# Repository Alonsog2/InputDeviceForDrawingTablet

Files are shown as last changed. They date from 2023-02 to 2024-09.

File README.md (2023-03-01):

# Input device for drawing tablet (and now, MIDI device too)

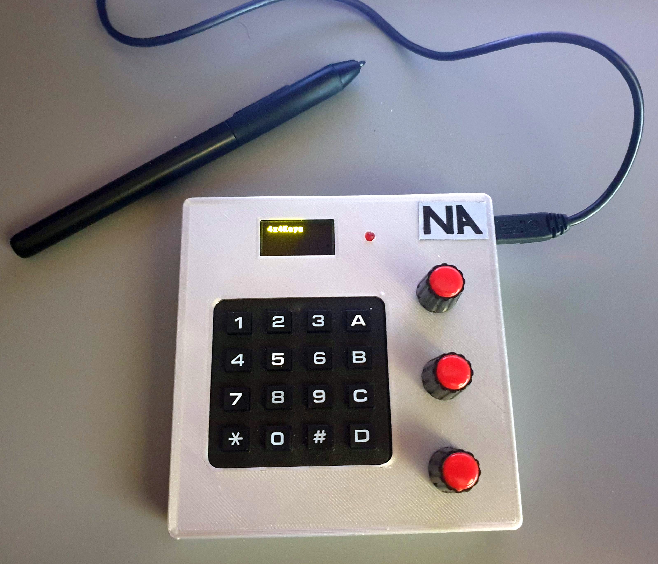
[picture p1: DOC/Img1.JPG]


This DIY device is recognized by any computer as a USB keyboard. Nor specific driver, neither other software is needed.
Inside, there is only an Arduino Pro Micro, a 4x4 keyboard matrix and 3 rotary encoders.

I use it with Krita but can be programmed with any key code combination, so it can work with any other drawing software.
The 16 keys and the 3 knobs/push buttons can send any combination of key codes.
The preprogrammed key codes can be modified easily, depending on your preferences, changing the corresponding program lines.

I have programmed the first knob for "rotate canvas" function (and reset the rotation if you press the knob)

The second knob is assigned for zooming (and reset the zoom to "fit page" pressing the knob)

The third knob is for resizing the brush. In this case, pushing the knob toggle the 'erase mode' of the brush.

Bear in mind that, in some cases, the shortcuts in my Krita setup are not the standard ones, so pay attention to this.

In this new version, a display shows the info about what key or action is performed. 

LocalShift function:
Now, the system can have to different sets of keys. Let's call them 'primary set' and 'secondary set'.
A key must be defined as 'LocalShift' (by default the key A) and it opperates as follow, allowing access to a different set of configurations for the rest of 15 keys.

Pressing once 'local shift' the system enters in temporary 'local shift' mode (the LED blinks), and after the next stroke in any key, the system will return to normal mode (and the LED turns off).

Pressing twice 'local shift' the system enters in 'local shift' mode (the LED turns on) , and remains in this mode until deactivated by a new press on 'local shift' and the system will return to normal mode (and the LED turns off).

A long press on 'local shift' will switch between 'normal mode' and 'Test mode' (the LED blinks less frequently). While in 'test mode' no keystrokes are sent to the computer but displayed on the screen. Handy for checking how all the keys are configured. To exit 'test mode', long-press 'local shift' again.

MIDI device:
Now, the system can act as a MIDI controller too. 
A long press (more than 2 seconds) on 'Knob #1' will switch between 'Keyboard mode' and 'MIDI mode'. In this case, the device will be recognized as a MIDI controller by the computer. All the parameters related to MIDI mode are defined in the setup file and are independent of the keyboard mode.

All the config parameters are located in the file 'Setup1.h'. It is possible to use different config files, such as 'Setup2.h'... etc., changing the corresponding line in the main program (just in case you have several devices with different configurations).

For more information, schematic, 3D printer file, etc. see the files in the DOC folder.

You can see a video with an example of use: [Example in youtube](https://youtu.be/WGJYHXOumJs)

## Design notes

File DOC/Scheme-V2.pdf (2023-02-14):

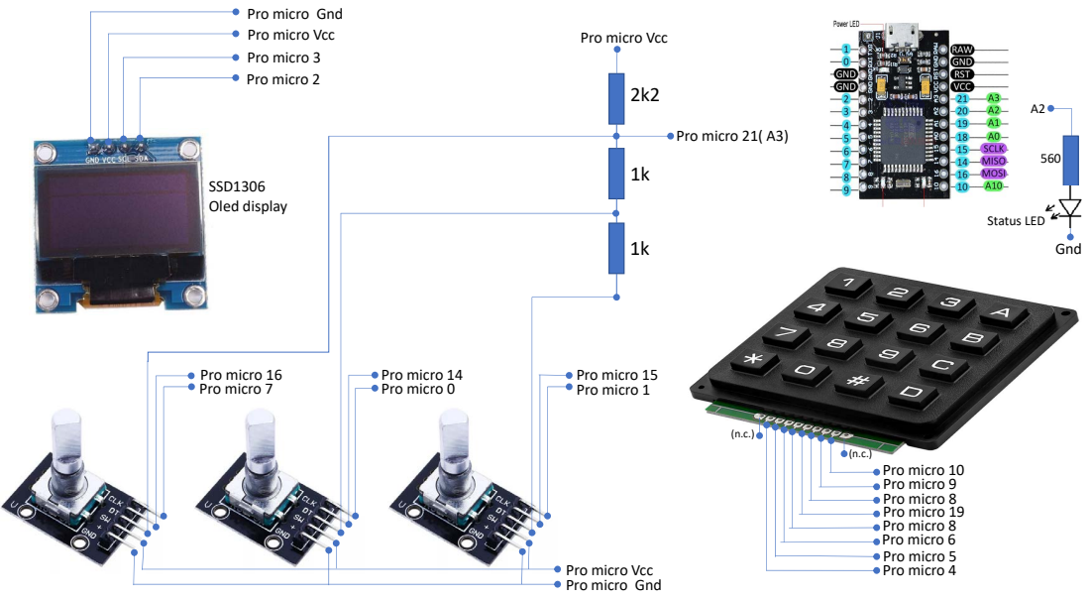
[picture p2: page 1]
Pro micro 21( A3); Pro micro 16 Pro micro 7; Pro micro 14 Pro micro 0; Pro micro 15 Pro micro 1; Pro micro 9 Pro micro 8 Pro micro 19 Pro micro 8 Pro micro 6 Pro micro 5 Pro micro 4; Pro micro 10; Gnd; Status LED; SSD1306 Oled display

Pro micro Gnd
Pro micro Vcc
Pro micro 3
Pro micro 2

# Key settings

Q (Freehand select. temp.) | T (Move tool temp.) | Ctrl‐D (Deselect) | Local Shift
Tab (Only canvas) | S (Isolate layer) | R (Select layer) | BackSpace (Fill with backColor)
Shift | Ctrl < (Shade color selector) | Z (Pie menu) | Ctrl SPC (Zoom)
Ctrl (Color picker) | Ctrl Z (Undo) | M (Mirror) | SPC (Pan canvas)

4 6

Rotate
canvas

7 9

Brush
size

‐ +

Zoom
canvas

5 (Reset rotation)

2 (Fit page)

E (Toggle eraser)

First press ‐> Temporary Shift mode Second press‐> Permanent Shift mode Third press ‐> Return to normal mode (main settings configuration , see previous page)

Long press ‐> Enter in Test mode (no keys are sent to the computer) Long press again ‐> Exit test mode

While in test mode ‐> Long press (2 seconds) “Reset rotation” button, change to MIDI mode

LocalShift:

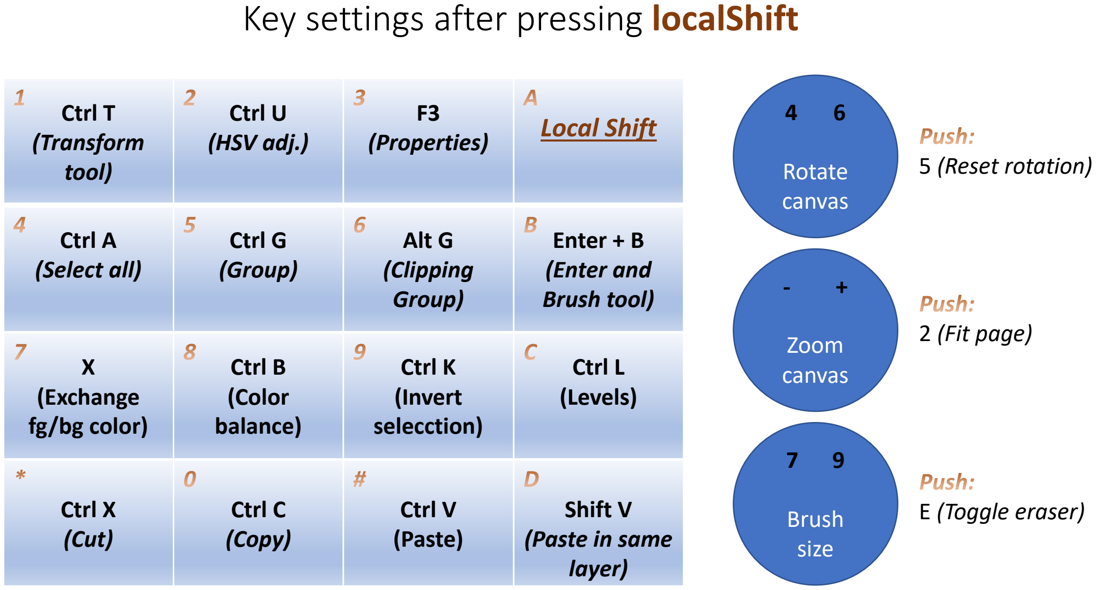
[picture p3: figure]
Key settings after pressing localShift; Ctrl T (Transform tool); Ctrl U (HSV adj.); F3 (Properties); Local Shift; X (Exchange fg/bg color); Ctrl B (Color balance); Ctrl K (Invert selecction); Ctrl L (Levels); Rotate canvas; Brush size; Zoom canvas; 5 (Reset rotation); 2 (Fit page); E (Toggle eraser)

Ctrl A (Select all) | Ctrl G (Group) | Alt G (Clipping Group) | Enter + B (Enter and Brush tool)
Ctrl X (Cut) | Ctrl C (Copy) | Ctrl V (Paste) | Shift V (Paste in same layer)

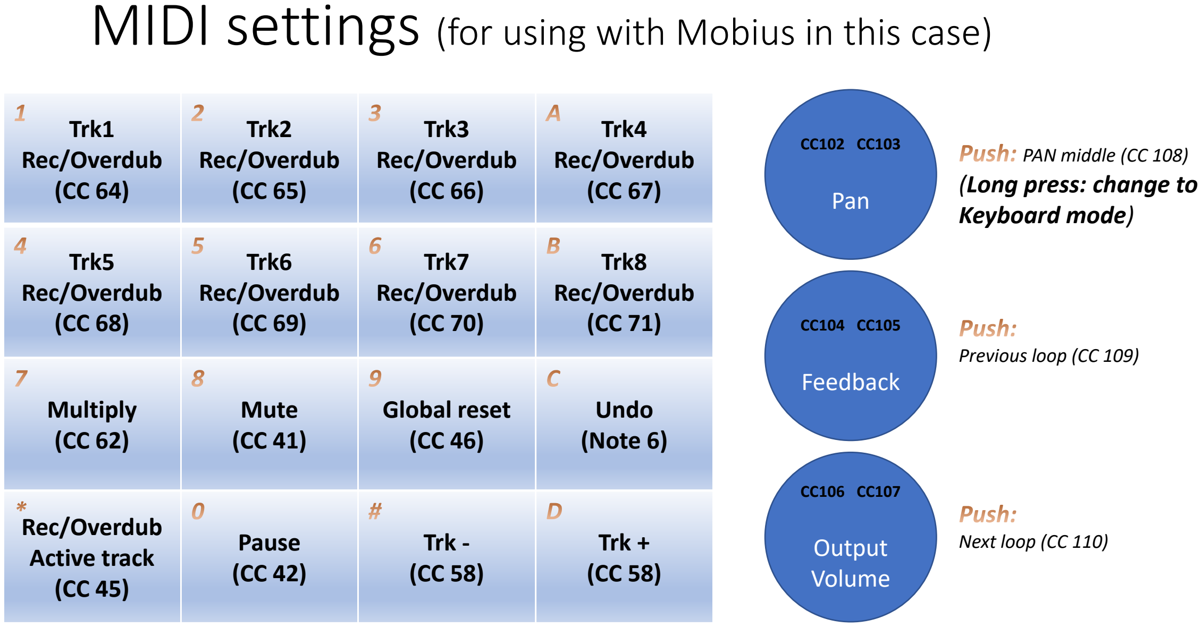
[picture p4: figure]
Trk1 Rec/Overdub (CC 64); Trk2 Rec/Overdub (CC 65); Trk3 Rec/Overdub (CC 66); Trk4 Rec/Overdub (CC 67); Trk5 Rec/Overdub (CC 68); Trk6 Rec/Overdub (CC 69); Trk7 Rec/Overdub (CC 70); Trk8 Rec/Overdub (CC 71); Multiply (CC 62); Mute (CC 41); Global reset (CC 46); Undo (Note 6); Rec/Overdub Active track (CC 45); Pause (CC 42); Trk ‐ (CC 58); Trk + (CC 58); Pan; Output Volume; Feedback; PAN middle (CC 108) (Long press: change to Keyboard mode); Previous loop (CC 109); Next loop (CC 110)

## MIDI settings (for using with Mobius in this case)

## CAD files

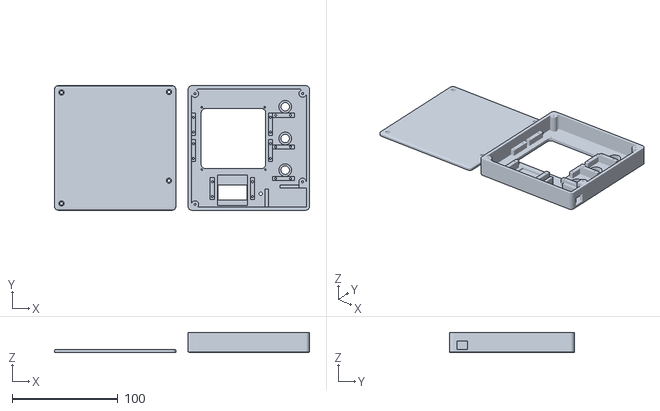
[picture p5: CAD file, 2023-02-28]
DOC/InputDeviceForDrawingTablet-3D-box.stl
241.5 x 118.1 x 19.0

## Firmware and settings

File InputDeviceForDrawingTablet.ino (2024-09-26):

/* This project as been made by Jose Ignacio Alonso
   For more information, visit https://github.com/Alonsog2/InputDeviceForDrawingTablet
*/


#define SETUP_TO_USE "Setup1.h"

//#define INIT_IN_ TEST_MODE           // uncomment this line while testing the sketch, to prevent sending keystrokes to the computer


#define CF(s) ((const __FlashStringHelper *)s)

///////////////////////////////////////////////////////////////////////////////   4X4 keyboard   ///////////////////////////////////////////////////////

#include <Keyboard.h>               // library for USB communication

#include <Keypad.h>                 // library for controlling 4x4 keys
const byte ROWS = 4; // rows
const byte COLS = 4; // columns
char keys[ROWS][COLS] = {           // characters behind number 9 are the next in the ASCII secuence, just to make easier the indexation (from 0 to 15)
  {'0', '1', '2', '3'},
  {'4', '5', '6', '7'},
  {'8', '9', ':', ';'},
  {'<', '=', '>', '?'}
};

enum LOCAL_SHIFT_MODES {
  NO_LOCAL_SHIFT = 0,
  LOCAL_SHIFT_TEMP,                         // Pressing once localShift key. Then, after pressing any other key, the system automaticaly return to NO_LOCAL_SHIFT mode
  LOCAL_SHIFT_LOCKED,                       // Pressing twice localShift key. Then the system remains in localShift mode until localShift key is pressed again.
};

LOCAL_SHIFT_MODES localShiftMode = NO_LOCAL_SHIFT;

#define millis_LED_LocalShift 150
#define millis_LED_TestMode_High 50
#define millis_LED_TestMode_Low 900
#define millis_LED_MidiMode 1000
#define millis_LONG_PRESS_SwitchMIDImode 2000

long lastMillis_LED_Status = 0;

char key;

//////////////////////////////////////////////////////////////////////  ROTARY ENCODERS  ///////////////////////////////////////////////////////////////

#include <Encoder.h>

#define N_ENCODERS 3

#define INX_ENCODER_UP 1
#define INX_ENCODER_DOWN 0

#define MILLIS_DISPLAYING_ENCODER_INFO 600
boolean bEncodersMoved = false;
unsigned long lastTimeEncoderMoved = 0;


//////////////////////////////////////////////////////////////////////   Analog buttons (3 keys readed in only one analogic input)  ////////////////////////

#include <AnalogMultiButton.h>

// set how many buttons you have connected
#define ENCODER_BUTTONS_TOTAL N_ENCODERS

// find out what the value of analogRead is when you press each of your buttons and put them in this array
// you can find this out by putting Serial.println(analogRead(ENCODER_BUTTONS_ANALOG_PIN)); in your loop() and opening the serial monitor to see the values
// make sure they are in order of smallest to largest
const int ENCODER_BUTTONS_VALUES[ENCODER_BUTTONS_TOTAL] = {0, 315, 482};

// you can also define constants for each of your buttons, which makes your code easier to read
// define these in the same order as the numbers in your BUTTONS_VALUES array, so whichever button has the smallest analogRead() number should come first
enum ENCODER_BUTTONS {
  ENCODER2_BUTTON = 0,
  ENCODER1_BUTTON,
  ENCODER0_BUTTON
};


#include SETUP_TO_USE

#include "MIDI.h"


Keypad keypad = Keypad( makeKeymap(keys), rowPins, colPins, ROWS, COLS );

// make an AnalogMultiButton object, pass in the pin, total and values array
AnalogMultiButton encoder_buttons(ENCODER_BUTTONS_ANALOG_PIN, ENCODER_BUTTONS_TOTAL, ENCODER_BUTTONS_VALUES);

#ifdef INIT_IN_ TEST_MODE
  boolean testMode = true;
#else
  boolean testMode = false;
#endif


#define SECONDS_UNTIL_SCREENSAVER_IF_SYSTEMUNLOCKED 300   // (300/60) = 5 minutes
#define SECONDS_UNTIL_SCREENSAVER_IF_SYSTEMLOCKED 5     

unsigned long lastTimeActionByUser = 0;
unsigned long millisIntervalUntilScreenSaverIfSystemUnlocked = (unsigned long)(SECONDS_UNTIL_SCREENSAVER_IF_SYSTEMUNLOCKED) * 1000;
unsigned long millisIntervalUntilScreenSaverIfSystemLocked = (unsigned long)(SECONDS_UNTIL_SCREENSAVER_IF_SYSTEMLOCKED) * 1000;
unsigned long millisIntervalScreenSaver = millisIntervalUntilScreenSaverIfSystemUnlocked;
boolean bScreenSaverON = false;
boolean bSystemLocked = false;



/////////////////////////////////////////////////////// setup //////////////////////////////////////////////////////////////

void setup() {
  Serial.begin(115200);
  delay(3000);
  Serial.println(F("Init"));

  if (DeviceModel != KEYBOARD_ONLY) {
    initMIDI();
  }

  if (bUseDisplay) {
    initDisplay();
  }

  //Switch off the serial port leds
  pinMode(LED_BUILTIN_TX, INPUT);
  pinMode(LED_BUILTIN_RX, INPUT);

  pinMode(pin_LED_Status, OUTPUT);                       // LED for localShift indication

  refreshLED_Status();

  keypad.setDebounceTime(50);

  Keyboard.begin();

  encoder_buttons.update();                              // just for clearing status

  Serial.println(F("EndSetup"));
}




/////////////////////////////////////////////////////// loop //////////////////////////////////////////////////////////////

void loop() {
  byte keyIndex;

  encoder_buttons.update();                                                                  // check encoder_buttons only once for the whole loop
  
  if (bCheckMIDIpedalIn4x4keysMode){                                                         // Checking MIDIpedal while in 4x4keys mode 
    if (encoder_buttons.onPressAndAfter(ENCODER2_BUTTON, 0)) {                               // 0= Detect only the first pressing
       pressedMIDIKey(actionsMIDIEncodersButtons, 2);                                        // MIDIpedal is button #2       
    }

    if (encoder_buttons.onRelease(ENCODER2_BUTTON)) {
      releasedMIDIKey(actionsMIDIEncodersButtons, 2);
      clearAreaBottomDisplay();
    }
  }

  unsigned long millisNow = millis();
  if ( abs(millisNow - lastTimeActionByUser) > millisIntervalScreenSaver ) {
    if (! bScreenSaverON) {
      clearAllDisplay(); 
      bScreenSaverON = true;
    }
    bSystemLocked = true;
  }

  if (bSystemLocked) {
    if (keypad.getKeys()) {
      for (int i = 0; i < LIST_MAX; i++) {                       // Scan the whole key list.
        if ( keypad.key[i].stateChanged ) {                      // Only find keys that have changed state.
          keyIndex = keypad.key[i].kchar - char('0');            // get the index from 0 to 15
          if (keyIndex == index_LocalShiftKey) {
            if (keypad.key[i].kstate == HOLD) {
              bSystemLocked = false;
            }
          }
        }
      }
      displayStatus();
      resetTimeScreenSaver();      
    }
    if (bSystemLocked) {
      millisIntervalScreenSaver = millisIntervalUntilScreenSaverIfSystemLocked;
      return;
    } else {
      millisIntervalScreenSaver = millisIntervalUntilScreenSaverIfSystemUnlocked;
    }
  }

  // Fills kpd.key[ ] array with up-to 10 active keys. Returns true if there are ANY active keys.
  if (keypad.getKeys()) {
    for (int i = 0; i < LIST_MAX; i++) {                       // Scan the whole key list.
      if ( keypad.key[i].stateChanged ) {                      // Only find keys that have changed state.
        resetTimeScreenSaver();
        bEncodersMoved = false;
        keyIndex = keypad.key[i].kchar - char('0');            // get the index from 0 to 15
        switch (keypad.key[i].kstate) {                        // Report active key state : IDLE, PRESSED, HOLD, or RELEASED
          case PRESSED:
            if (MIDImode) {
              pressedMIDIKey(actionsMIDI, keyIndex);
              break;
            }

            if (keyIndex == index_LocalShiftKey) {
              switch (localShiftMode) {
                case NO_LOCAL_SHIFT:
                  localShiftMode = (testMode) ? LOCAL_SHIFT_LOCKED : LOCAL_SHIFT_TEMP;  // In testMode, always go to LOCAL_SHIFT_LOCKED (skiping LOCAL_SHIFT_TEMP)
                  break;
                case LOCAL_SHIFT_TEMP:
                  localShiftMode = LOCAL_SHIFT_LOCKED;
                  lastMillis_LED_Status = 0;
                  break;
                case LOCAL_SHIFT_LOCKED:
                  localShiftMode = NO_LOCAL_SHIFT;
                  break;
              }
              Keyboard.releaseAll();                         // just in case some other previous key still pressed...
              clearAllDisplay();
              displayStatus();
              break;
            }

            if (! testMode) {
              sendKeyPressed( ( (localShiftMode == NO_LOCAL_SHIFT) ? actions : actions_LocalShift), keyIndex);
            }

            if (localShiftMode == NO_LOCAL_SHIFT) {
              displayKeyLabel( CF( actions_labels[keyIndex]));
            } else {
              displayKeyLabel( CF( actions_LocalShift_labels[keyIndex]));
            }
            break;

          case HOLD:
            if (testModeEnabled && (keyIndex == index_LocalShiftKey)) {  // Switch test mode
              Keyboard.releaseAll();                                     // just in case some other previous key still pressed...
              localShiftMode = NO_LOCAL_SHIFT;                           // After enter or exit testMode, always return to NO_LOCAL_SHIFT modee2
              testMode = !testMode;
              displayStatus();
            }
            break;

          case RELEASED:
            if (MIDImode) {
              releasedMIDIKey(actionsMIDI, keyIndex);
              clearAreaBottomDisplay();
              break;
            }

            if (keyIndex == index_LocalShiftKey) {
              Keyboard.releaseAll();                        // just in case some other previous key still pressed...
              break;
            }
            if (localShiftMode == LOCAL_SHIFT_TEMP) {
              localShiftMode = NO_LOCAL_SHIFT;
              Keyboard.releaseAll();
              displayStatus();
              refreshLED_Status();
            }

            sendKeyDepressed( ( (localShiftMode) ? actions_LocalShift : actions), keyIndex);
            clearAreaBottomDisplay();
            break;

            //case IDLE:
            //  msg = " IDLE.";
            //  break;
        }

        //Serial.print(F("Key "));
        //Serial.print(keypad.key[i].kchar);
      }
    }
  }
  refreshLED_Status();

  // check the ENCODERS
  if (bUseRotaryEncoders) {
    long newPositionEncoder;

    for (int nEncoder = 0; nEncoder < N_ENCODERS ; nEncoder++) {
      int indexUpDown = -1;

      newPositionEncoder = chekEncoderN(nEncoder);
      if (newPositionEncoder > 1) indexUpDown = INX_ENCODER_DOWN;
      if (newPositionEncoder < -1) indexUpDown = INX_ENCODER_UP;
      if (indexUpDown != -1) {
        if (MIDImode) { /////////////////////////////////////////////////////////////////// MIDI mode /////////////////////////////////////////
          if (MIDIencodersEqualUpDownCC[nEncoder]) { // MIDI encoder EqualUpDownCC
            byte channel = (actionsMIDIEncoders[nEncoder][MIDI_CHANNEL] == 0) ? GLOBAL_MIDI_CHANNEL : actionsMIDIEncoders[nEncoder][MIDI_CHANNEL];
            int value = MIDIvalRotaryEncoders[nEncoder];
            if (indexUpDown == INX_ENCODER_UP) {
              value += actionsMIDIEncoders[nEncoder][MIDI_IncrDecrStep];
              if (value > actionsMIDIEncoders[nEncoder][MIDI_ValMax]) {
                value = actionsMIDIEncoders[nEncoder][MIDI_ValMax];
              }
            }
            if (indexUpDown == INX_ENCODER_DOWN) {
              value -= actionsMIDIEncoders[nEncoder][MIDI_IncrDecrStep];
              if (value < actionsMIDIEncoders[nEncoder][MIDI_ValMin]) {
                value = actionsMIDIEncoders[nEncoder][MIDI_ValMin];
              }
            }

            MIDIvalRotaryEncoders[nEncoder] = value;
            sendCtrlChange_USB(actionsMIDIEncoders[nEncoder][MIDI_nCC], value, channel);
          } else {  // Dual UP/DOWN
            pressedMIDIKey( ((indexUpDown == INX_ENCODER_DOWN) ? actionsMIDIEncodersDOWN : actionsMIDIEncodersUP ),  nEncoder);
          }
          // End MIDI

        } else { ///////////////////////////////////////////////////////////////////// KEYBOARD mode /////////////////////////////////////////
          if (! testMode) {
            Keyboard.press(actions1Encoders[nEncoder][indexUpDown]);
            if (actions2Encoders[nEncoder][indexUpDown] != 0) {                    // if the value is other than 0, send it
              Keyboard.press(actions2Encoders[nEncoder][indexUpDown] );
            }
          }

          displayKeyLabel( (indexUpDown == INX_ENCODER_UP) ? CF(actionsEncoderIncr_labels[nEncoder]) : CF(actionsEncoderDecr_labels[nEncoder]));

          Keyboard.releaseAll();
          // End Keyboard
        }

        resetEncoderN(nEncoder);
        resetTimeScreenSaver();
        lastTimeEncoderMoved = millis();
        bEncodersMoved = true;
      }
    }
  }
  //


  // check ENCODER_BUTTONS  ////////////////////////////////////////////////////////////////////////////////////////
  if (bUseEncoderButtons) {
    int keyIndex = -1;
    //encoder_buttons has been updated at the begining of the loop

    // Check possible switch Keyboard/MIDI mode //////////////////////////////////
    if (DeviceModel == KEYBOARD_AND_MIDI || DeviceModel == MIDI_AND_KEYBOARD) {              // Device can switch between Keyboard and MIDI ?
      if (encoder_buttons.onPressAfter(ENCODER0_BUTTON, millis_LONG_PRESS_SwitchMIDImode)) { // The defined enconder for switching is pressed more than xxxx millis ?
        Keyboard.releaseAll();
        resetTimeScreenSaver();
        bEncodersMoved = false;
        switchMIDIAndKeyboardMode();
      }
    } ////////////////////////////////////////////////////////////////////////////

    if (encoder_buttons.onPressAndAfter(ENCODER0_BUTTON, 0)) {   // 0= Detect only the first pressing
      keyIndex = 0;
    } else if (encoder_buttons.onPressAndAfter(ENCODER1_BUTTON, 0)) {
      keyIndex = 1;
    } else if (encoder_buttons.onPressAndAfter(ENCODER2_BUTTON, 0) && (!bCheckMIDIpedalIn4x4keysMode)) {
      keyIndex = 2;
    }

    if (keyIndex != -1) {
      resetTimeScreenSaver();
      bEncodersMoved = false;
      if (MIDImode) {
        pressedMIDIKey(actionsMIDIEncodersButtons, keyIndex);
      } else {
        if (! testMode) {
          sendKeyPressed(actionsEncoder_Buttons, keyIndex);
        }
        displayKeyLabel( CF( actionsEncoder_labels[keyIndex]));
      }
    }

    // check if some encoder_button has been DEPRESSED
    keyIndex = -1;
    if (encoder_buttons.onRelease(ENCODER0_BUTTON)) {
      keyIndex = 0;
    } else if (encoder_buttons.onRelease(ENCODER1_BUTTON)) {
      keyIndex = 1;
    } else if (encoder_buttons.onRelease(ENCODER2_BUTTON) && (!bCheckMIDIpedalIn4x4keysMode)) {
      keyIndex = 2;
    }

    if (keyIndex != -1) {
      resetTimeScreenSaver();
      bEncodersMoved = false;
      if (MIDImode) {                                            // MIDI mode
        releasedMIDIKey(actionsMIDIEncodersButtons, keyIndex);
      } else {                                                   // Keyboard
        if (! testMode) {
          sendKeyDepressed(actionsEncoder_Buttons, keyIndex);
        }
      }
      clearAreaBottomDisplay();
    }

  } // End ENCODER_BUTTONS

  checklastTimeEncoderMoved();

} // loop




///////////////////////////////////////////////////////// other functions //////////////////////////////////////////////////////////////

void sendKeyPressed(char acts[ROWS * COLS][2], int keyIndex) {
  Keyboard.press(acts[keyIndex][0]);           // send the first action for the corresponding key
  if (acts[keyIndex][1] != 0) {                 // send the second value if not 0
    Keyboard.press(acts[keyIndex][1]);
  }
}



void sendKeyDepressed(char acts[ROWS * COLS][2], int keyIndex) {
  if (acts[keyIndex][1] != 0) {                  // invert the order when releasing the keys, send actions2 first (if needed)
    Keyboard.release(acts[keyIndex][1]);
  }
  Keyboard.release(acts[keyIndex][0]);           // and then actions1
}



long chekEncoderN(int nEncoder) {
  switch (nEncoder) {
    case 0:
      return myEnc0.read();
      break;
    case 1:
      return myEnc1.read();
      break;
    case 2:
      return myEnc2.read();
      break;
      return 0;
  }
}



void resetEncoderN(int nEncoder) {
  switch (nEncoder) {
    case 0:
      myEnc0.write(0);
      break;
    case 1:
      myEnc1.write(0);
      break;
    case 2:
      myEnc2.write(0);
      break;
  }
}



void refreshLED_Status() {
  static boolean prevStatusLed = false;
  static boolean prevStatusLed_TestMode = false;
  static byte nPulseTest = 0;
  boolean newStatusLed;
  boolean newStatusLed_TestMode;

  if (MIDImode) {                                                                 // MIDI
    refreshLED_inMIDImode();
    return;
  }

  if (testMode) {                                                                 // TestMode
    newStatusLed = prevStatusLed;
    switch (nPulseTest) {
      case 0:                                                                   // NO_LOCAL_SHIFT status -> One short blink and a large pause
        if (millis() > (lastMillis_LED_Status + millis_LED_TestMode_High) ) {
          lastMillis_LED_Status = millis();
          newStatusLed = false;
          nPulseTest ++;
        }
        break;
      case 1:
        if (millis() > (lastMillis_LED_Status + millis_LED_TestMode_High) ) {
          lastMillis_LED_Status = millis();
          if (localShiftMode != NO_LOCAL_SHIFT) {                               // Other status than NO_LOCAL_SHIFT -> Two short blink and a large pause
            newStatusLed = true;
          }
          nPulseTest ++;
        }
        break;
      case 2:
        if (millis() > (lastMillis_LED_Status + millis_LED_TestMode_High) ) {
          lastMillis_LED_Status = millis();
          newStatusLed = false;
          nPulseTest ++;
        }
        break;
      case 3:
        if (millis() > (lastMillis_LED_Status + millis_LED_TestMode_Low) ) {
          lastMillis_LED_Status = millis();
          newStatusLed = true;
          nPulseTest = 0;
        }
        break;
    }

  } else {                                                                   // NO testMode (normal)

    if (localShiftMode == LOCAL_SHIFT_TEMP) {                                // if LOCAL_SHIFT_TEMP mode, blink led
      newStatusLed = prevStatusLed;
      if (millis() > (lastMillis_LED_Status + millis_LED_LocalShift) ) {
        lastMillis_LED_Status = millis();
        newStatusLed = (! newStatusLed);
      }
    } else {
      newStatusLed = ( (localShiftMode == NO_LOCAL_SHIFT) ? LOW : HIGH);     // other modes than LOCAL_SHIFT_TEMP
    }
  }

  digitalWrite(pin_LED_Status, newStatusLed);
  prevStatusLed = newStatusLed;
}



void refreshLED_inMIDImode() {
  static boolean prevStatusLed = false;
  boolean newStatusLed;
  newStatusLed = prevStatusLed;
  if (millis() > (lastMillis_LED_Status + millis_LED_MidiMode) ) {
    lastMillis_LED_Status = millis();
    newStatusLed = (! newStatusLed);
    digitalWrite(pin_LED_Status, newStatusLed);
    prevStatusLed = newStatusLed;
  }
}


void switchMIDIAndKeyboardMode() {
  MIDImode = !MIDImode;
  if (MIDImode) {
    digitalWrite(pin_LED_Status, HIGH);                                      // LED ON;
  } else {
    sendMIDIreset();
    localShiftMode = NO_LOCAL_SHIFT;                                         // will refresh LED status inside 'loop'
    testMode = false;
  }
  displayStatus();
}



void checklastTimeEncoderMoved() {
  if (bEncodersMoved) {
    if ( abs(millis() - lastTimeEncoderMoved) > MILLIS_DISPLAYING_ENCODER_INFO ) {
      clearAreaBottomDisplay();
      bEncodersMoved = false;
    }
  }
}



void resetTimeScreenSaver() {
  bScreenSaverON = false;
  lastTimeActionByUser = millis();
}

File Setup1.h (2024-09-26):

//
// Setup1 (Define in the main tab the "SetupX.h" to use)
//


enum DEVICE_MODELS {
  KEYBOARD_ONLY,
  MIDI_ONLY,
  KEYBOARD_AND_MIDI,                  // Starts in keyboard mode but allows switch to MIDI  
  MIDI_AND_KEYBOARD                   // Starts in MIDI mode but allows switch to keyboard
};                                    // Long press EncoderButton#0 switch mode

byte DeviceModel = KEYBOARD_AND_MIDI;

boolean bUseDisplay = true;          // PINs 2,3 are used by Wire library (SDA, SCL in Display)

boolean bUseRotaryEncoders = true;
boolean bUseEncoderButtons = true;
boolean bCheckMIDIpedalIn4x4keysMode =false;


#define pin_LED_Status A2


/////////////////////////////////////////////////////////////////////////////////////////////////////////////////////////
///////////////////////////////////////////////////////////////////// 4x4 Keyboard Section //////////////////////////////
/////////////////////////////////////////////////////////////////////////////////////////////////////////////////////////

// pins to use in 4x4 keyboard
const byte rowPins[ROWS] = {A1, 8, 9, 10};         //rows
const byte colPins[COLS] = {A0, 4, 5, 6};          //columns


const byte index_LocalShiftKey = 3;                // index from 0 to 15 of the key that acts a 'shift' key. If -1 then no localShiftKey 

// Actions for 4x4 keyboard
const char actions[ROWS * COLS][2] = {      // code sent when a key is pressed. if second value is other than 0 send it
  {'q', 0},            {'t', 0},             {KEY_LEFT_CTRL, 'd'},{'|', 0},
  {KEY_TAB, 0},        {'s', 0},             {'r', 0},            {KEY_BACKSPACE, 0},
  {KEY_LEFT_SHIFT, 0}, {'N', 0},             {'z', 0},            {KEY_LEFT_CTRL, ' '},
  {KEY_LEFT_CTRL, 0},  {KEY_LEFT_CTRL, 'z'}, {'m', 0},   {' ',0}
};

const char ACT_LABEL_1[] PROGMEM = "FreeHand\nSelectTmp.";
const char ACT_LABEL_2[] PROGMEM = "Move temp.";
const char ACT_LABEL_3[] PROGMEM = "Unselect\nAll";
const char ACT_LABEL_4[] PROGMEM = "LocalShift";
const char ACT_LABEL_5[] PROGMEM = "Only\ncanvas";
const char ACT_LABEL_6[] PROGMEM = "Isolate\nlayer";
const char ACT_LABEL_7[] PROGMEM = "Select\nlayer";
const char ACT_LABEL_8[] PROGMEM = "BackSpace\nFillBbgCol";
const char ACT_LABEL_9[] PROGMEM = "Shift\nResiz.Brsh";
const char ACT_LABEL_10[] PROGMEM = "ShadeColor\nselector";
const char ACT_LABEL_11[] PROGMEM = "Pie menu";
const char ACT_LABEL_12[] PROGMEM = "Zoom\n(Ctrl+SPC)";
const char ACT_LABEL_13[] PROGMEM = "Color pick\n(Ctrl)";
const char ACT_LABEL_14[] PROGMEM = "Undo\n(Ctrl Z)";
const char ACT_LABEL_15[] PROGMEM = "Mirror\n(M)";
const char ACT_LABEL_16[] PROGMEM = "SPC";

const char* const actions_labels[ROWS * COLS] = {
    ACT_LABEL_1,
    ACT_LABEL_2,
    ACT_LABEL_3,
    ACT_LABEL_4,
    ACT_LABEL_5,
    ACT_LABEL_6,
    ACT_LABEL_7,
    ACT_LABEL_8,
    ACT_LABEL_9,
    ACT_LABEL_10,
    ACT_LABEL_11,
    ACT_LABEL_12,
    ACT_LABEL_13,
    ACT_LABEL_14,
    ACT_LABEL_15,
    ACT_LABEL_16
};


// Next actions are active when localShiftKey has been pressed, insted of the 'actions' array. 
const char actions_LocalShift[ROWS * COLS][2] = {  // code sent when a key is pressed. if second value is other than 0 send it
  {KEY_LEFT_CTRL, 't'}, {KEY_LEFT_CTRL, 'u'}, {KEY_F3, 0},          {'|',0},
  {KEY_LEFT_CTRL, 'a'}, {KEY_LEFT_CTRL, 'g'}, {KEY_LEFT_ALT, 'g'},  {0xB0, 'b'},
  {'x', 0},             {KEY_LEFT_CTRL, 'b'}, {KEY_LEFT_CTRL, 'k'}, {KEY_LEFT_CTRL, 'l'},
  {KEY_LEFT_CTRL, 'x'}, {KEY_LEFT_CTRL, 'c'}, {KEY_LEFT_CTRL, 'v'}, {KEY_LEFT_SHIFT, 'v'}
};

const char ACT_SHIFT_LABEL_1[] PROGMEM = "Transform\nTool\n(Ctrl T)";
const char ACT_SHIFT_LABEL_2[] PROGMEM = "HVS\nadjust\n(Ctrl U)";
const char ACT_SHIFT_LABEL_3[] PROGMEM = "Properties\nF3";
const char ACT_SHIFT_LABEL_4[] PROGMEM = "LocalShift";
const char ACT_SHIFT_LABEL_5[] PROGMEM = "Select all\n(Ctrl A)";
const char ACT_SHIFT_LABEL_6[] PROGMEM = "Group\n(Ctrl G)";
const char ACT_SHIFT_LABEL_7[] PROGMEM = "Clip Group\n(Alt G)";
const char ACT_SHIFT_LABEL_8[] PROGMEM = "Enter + B\n(Enter and\nsel.Brush)";
const char ACT_SHIFT_LABEL_9[] PROGMEM = "Exch Fg/Bg\ncolor\n(X)";
const char ACT_SHIFT_LABEL_10[] PROGMEM = "ColBalance\n(Ctrl B)";
const char ACT_SHIFT_LABEL_11[] PROGMEM = "Invert\nselection\n(Ctrl K)";
const char ACT_SHIFT_LABEL_12[] PROGMEM = "Levels\n(Ctrl L)";
const char ACT_SHIFT_LABEL_13[] PROGMEM = "Cut\n(Ctrl X)";
const char ACT_SHIFT_LABEL_14[] PROGMEM = "Copy\n(Ctrl C)";
const char ACT_SHIFT_LABEL_15[] PROGMEM = "Paste\n(Ctrl v))";
const char ACT_SHIFT_LABEL_16[] PROGMEM = "Paste in\nsame layer";

const char* const actions_LocalShift_labels[ROWS * COLS] = {
    ACT_SHIFT_LABEL_1,
    ACT_SHIFT_LABEL_2,
    ACT_SHIFT_LABEL_3,
    ACT_SHIFT_LABEL_4,
    ACT_SHIFT_LABEL_5,
    ACT_SHIFT_LABEL_6,
    ACT_SHIFT_LABEL_7,
    ACT_SHIFT_LABEL_8,
    ACT_SHIFT_LABEL_9,
    ACT_SHIFT_LABEL_10,
    ACT_SHIFT_LABEL_11,
    ACT_SHIFT_LABEL_12,
    ACT_SHIFT_LABEL_13,
    ACT_SHIFT_LABEL_14,
    ACT_SHIFT_LABEL_15,
    ACT_SHIFT_LABEL_16
};



////////////////////////////////////////////////////////////// ROTARY ENCODERS /////////////////////////////////////////////////////

// Change these two numbers to the PINs connected to your encoder.
//   Best Performance: both pins have interrupt capability
//   Good Performance: only the first pin has interrupt capability
//   Low Performance:  neither pin has interrupt capability
/////
Encoder myEnc0(1, 15);
Encoder myEnc1(0, 14);
Encoder myEnc2(7, 16);
//   avoid using pins with LEDs attached

// Analog PIN for use with the three encoder buttons
const byte ENCODER_BUTTONS_ANALOG_PIN = A3;

// Actions for rotary encoders
const char actions1Encoders[N_ENCODERS][2] = { // Codes sent by the encoders (index [n][INX_ENCODER_UP]=UP or index [n][INX_ENCODER_DOWN]=DOWN)
  {'4',  '6'},                                 // Rotation
  {222,  223},                                 // 223=+ 222=-  Zoom
  {'7',  '9'}                                  // Brush size (not standard krita shortcut. Must be assigned in krita too)
};

const char actions2Encoders[N_ENCODERS][2] = { // second code to send, if needed (the value is other than 0)
  {0,  0},
  {0,  0}, 
  {0,  0}
};

const char ACT_ENC_INCR_LABEL_1[] PROGMEM = "Rotation\nRIGHT";
const char ACT_ENC_INCR_LABEL_2[] PROGMEM = "Rotation\nIN";
const char ACT_ENC_INCR_LABEL_3[] PROGMEM = "Brush\nsize +";

const char* const actionsEncoderIncr_labels[ROWS * COLS] = {
    ACT_ENC_INCR_LABEL_1,
    ACT_ENC_INCR_LABEL_2,
    ACT_ENC_INCR_LABEL_3
};

const char ACT_ENC_DECR_LABEL_1[] PROGMEM = "Rotation\nLEFT";
const char ACT_ENC_DECR_LABEL_2[] PROGMEM = "Rotation\nOUT";
const char ACT_ENC_DECR_LABEL_3[] PROGMEM = "Brush\nsize -";

const char* const actionsEncoderDecr_labels[ROWS * COLS] = {
    ACT_ENC_DECR_LABEL_1,
    ACT_ENC_DECR_LABEL_2,
    ACT_ENC_DECR_LABEL_3
};
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

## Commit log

2022-12-21 añadidos Rotary Encoders
2022-12-24 nueva pestaña con las asignaciones de teclas y act. doc
2022-12-29 añadida detección de liberación de los pulsadores de los encoders
2023-01-02 cambio de nombre
2023-01-15 added LED and three-state localShift
2023-01-27 2 LED for status (Shift and TestMode)
2023-01-28 LED bicolor
2023-02-01 avoid String type (cause problems with (little) memory in proMicro)
    [Display.ino, InputDeviceForDrawingTablet.ino, Setup1.h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]
2023-02-05 MIDI Rotary encoders can behave as buttons step by step
2023-02-13 All encoders use 'int' pin
2023-02-28 act stl 3d
    [InputDeviceForDrawingTablet-3D-box.stl]
2024-08-21 Agregado bloqueo de pantalla al salvapantallas. Se desbloquea con pulsación larga de LOCAL_SHIFT
2024-09-26 act button 1 = select brush
